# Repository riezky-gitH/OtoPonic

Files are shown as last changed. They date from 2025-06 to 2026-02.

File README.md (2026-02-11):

# Otomatisasi Hidroponik Berbasis IoT dengan Kendali Jarak Jauh dan Aplikasi Real-Time.
### Solusi Pertanian Cerdas Masa Kini
<p align="center">
  
</p>

## Daftar Isi

1. [Deskripsi Produk](https://github.com/riezky-gitH/OtoPonic#deskripsi-produk)
2. [Struktur Tim](https://github.com/riezky-gitH/OtoPonic#team-member)
3. [Tujuan Produk](https://github.com/riezky-gitH/OtoPonic#tujuan)
4. [Keunggulan Produk](https://github.com/riezky-gitH/OtoPonic#keunggulan)
5. [Potensi Pengembangan](https://github.com/riezky-gitH/OtoPonic#potensi-pengembangan)
6. [Kolaborasi & Dukungan](https://github.com/riezky-gitH/OtoPonic#kolaborasi--dukungan)
7. [Hardware](https://github.com/riezky-gitH/OtoPonic#hardware)
8. [Software](https://github.com/riezky-gitH/OtoPonic#software)
9. [Aplikasi OtoPonic](https://github.com/riezky-gitH/OtoPonic#aplikasi-otoponic)
10. [Hubungi Kami](https://github.com/riezky-gitH/OtoPonic#hubungi-kami)

## Deskripsi Produk
**OtoPonic** adalah solusi pertanian cerdas berbasis IoT yang dirancang untuk mengotomatisasikan hidroponik dengan fitur pemantauan real-time dan kendali jarak jauh melalui aplikasi atau web. Sistem ini mampu memantau berbagai parameter penting seperti pH air, kadar nutrisi, suhu air, serta batas ketinggian air dalam pipa hidroponik. OtoPonic dilengkapi dengan fitur kontrol otomatis, seperti aktivasi pompa nutrisi saat kadar terlalu rendah, pengaturan pH air dengan pompa pH up/down, dan penyiraman atau pengurasan otomatis dalam instalasi hidroponik. Selain itu, pengguna juga dapat mengontrol sistem secara manual melalui dashboard yang intuitif serta menerima notifikasi saat terjadi kondisi abnormal. Proyek ini bertujuan untuk meningkatkan efisiensi dan kenyamanan dalam bercocok tanam hidroponik, terutama bagi pengguna yang ingin memantau dan mengelola kebun mereka dari jarak jauh secara praktis dan real-time.

## Support By 
>- Dosen Pengampu : Akhmad Hendriawan ST., MT. (NIP.197501272002121003)
>- Mata kuliah : Mikrokontroller
>- Program Studi : D4 Teknik Elektronika
>- Politeknik Elektronika Negeri Surabaya<br>

## Team Member
| NRP | Nama | Jobdesk | Akun |
| :---:|:---:| :---:| :-----:|
| 2123600003 | Taufiq  |  UI/UX Designer | [Taufiq](https://github.com/Raditya-G)
| 2123600006 | Auliya | UI/UX Designer | [Auilya](https://github.com/auliyarzk/)
| 2123600017 | Brian | Programmer | [Brian](https://github.com/brianrjg)
| 2123600018 | Riezky | Project Manager | [Riezky](https://github.com/riezky-gitH)
| 2123600020 | Subkhi | Hardware Developer | [Subkhi](https://github.com/subkhiMuhammad)
| 2123600024 | Alwan | 3D Designer |[Alwan](https://github.com/alwan441)

## Foto Anggota Tim 


## Tujuan
- **Mempermudah perawatan kebun hidroponik** dengan sistem otomatis yang mengatur pH, nutrisi, dan penyiraman secara mandiri.
- **Memantau kondisi tanaman secara real-time** melalui aplikasi atau web, kapan saja dan di mana saja.
- **Memberikan kontrol penuh jarak jauh**, sehingga pengguna bisa mengelola kebun tanpa harus selalu berada di lokasi.
- **Meningkatkan efisiensi dan hasil panen** dengan pengelolaan nutrisi dan air yang lebih akurat dan stabil.
- **Cocok untuk semua kalangan**, mulai dari petani pemula hingga profesional yang ingin solusi praktis dan modern.

## Keunggulan

- **Integrasi IoT** yang kuat dengan adanya sensor dan komunikasi data berbasis GSM untuk pemantauan jarak jauh yang stabil
- **Kontrol manual & otomatis** yang dapat memberikan fleksibilitas
- **Antarmuka pengguna** yang intuitif dalam penggunaan UI/UX
- **Mendukung keberlanjutan & efisiensi energi** dalam mengurangi limbah air dan penggunaa sumber daya berlebihan

## Potensi Pengembangan OtoPonic
- **IoT Cloud** – Akses global & notifikasi real-time.
- **Peringatan WhatsApp/SMS** – Info langsung saat kondisi kritis.
- **AI & Machine Learning** – Prediksi kebutuhan nutrisi & pertumbuhan.
- **Smart City Ready** – Siap terintegrasi dengan infrastruktur kota pintar.
- **Dashboard Analytics** – Visualisasi data & performa tanaman.

## Kolaborasi & Dukungan
- **Investor Teknologi** – Skala produksi & fitur lebih canggih.
- **Startup/R&D** – Kolaborasi pengembangan sensor & AI.
- **Kampus/Inkubator** – Edukasi & riset pertanian cerdas.
- **Pemerintah & Komunitas** – Implementasi urban farming pintar.
- **UMKM & Petani Modern** – Otomatisasi untuk hasil lebih optimal.
  
## Hardware
### 1. Desain Skematik


### 2. Desain PCB


### 3. 3D Desain PCB


## Software
### 1. Blok Diagram


### 2. Diagram Arsitektur Sistem

## Aplikasi OtoPonic
### 1. Login

### 2. Dashboard

### 3. Data Riwayat

### 4. Parameter Setting
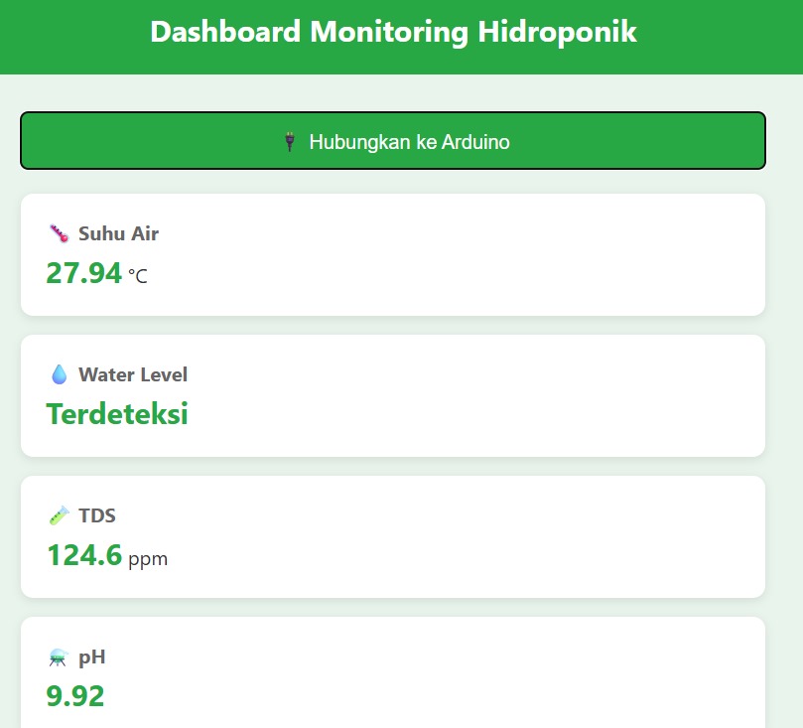
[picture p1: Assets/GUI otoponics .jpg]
)

## Hubungi Kami

Untuk kerja sama, pertanyaan, atau demo proyek:

**Email Project Manager**: [riezky.mochammad07@gmail.com](mailto:riezky.mochammad07@gmail.com)

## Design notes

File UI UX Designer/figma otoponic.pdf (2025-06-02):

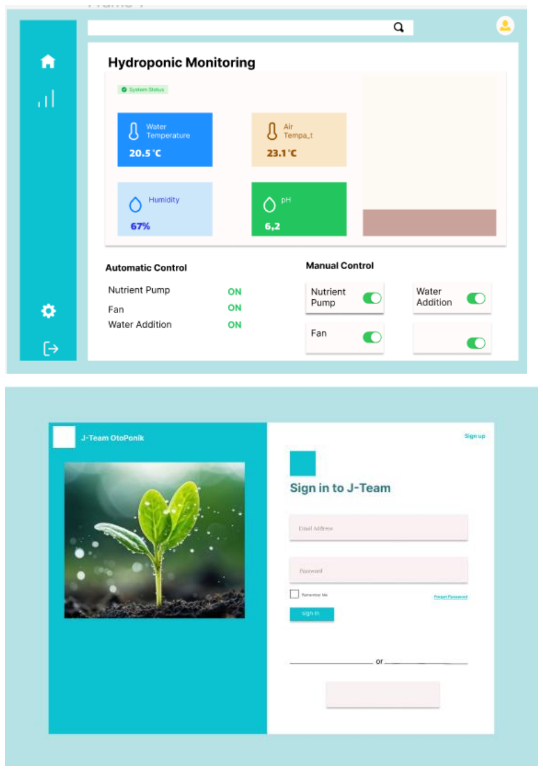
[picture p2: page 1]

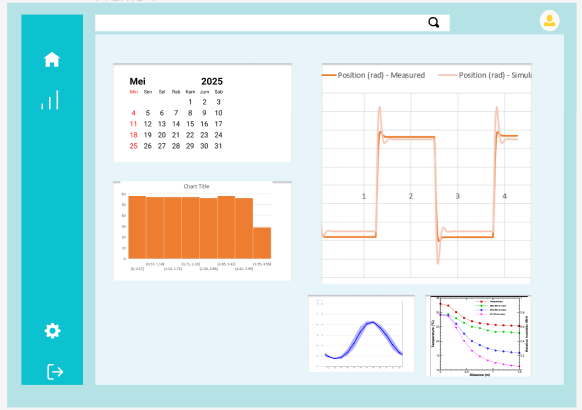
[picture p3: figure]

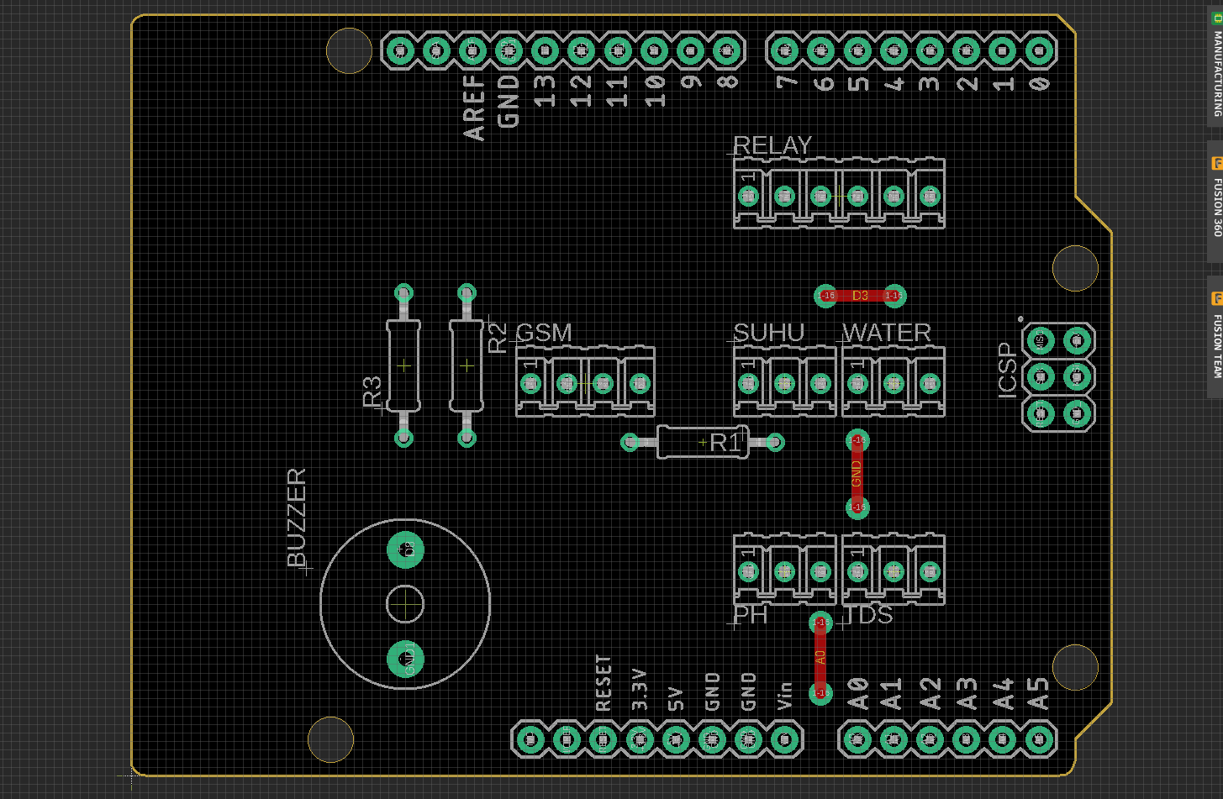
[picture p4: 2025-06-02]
Hardware/PCB/Preview Board.png

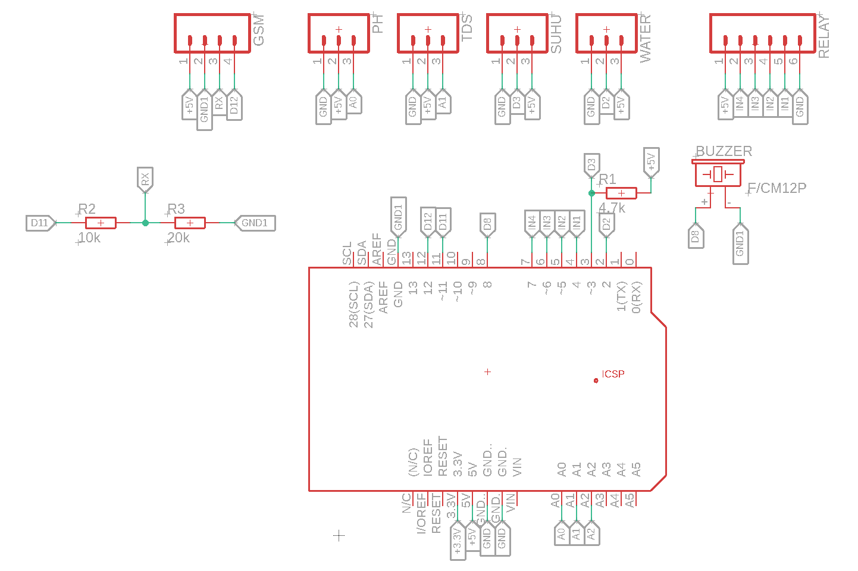
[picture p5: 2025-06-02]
Hardware/PCB/Preview Skematik.png

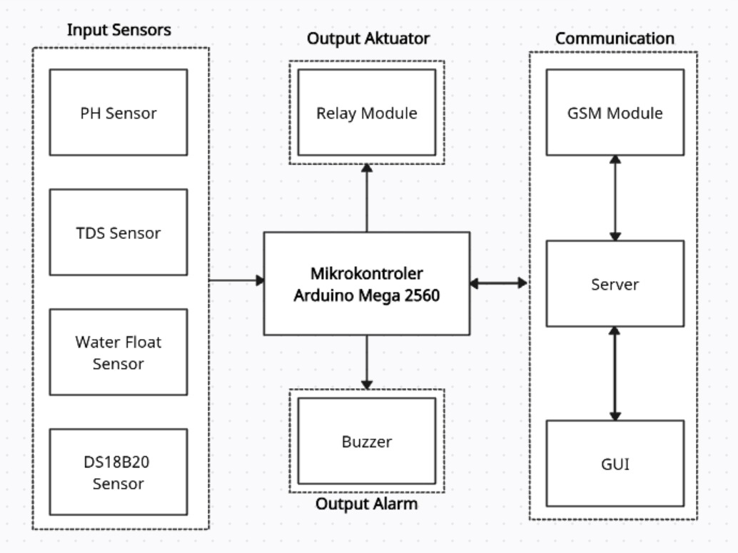
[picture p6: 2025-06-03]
Hardware/Dokumentasi Teknis/Blok Diagram.jpg

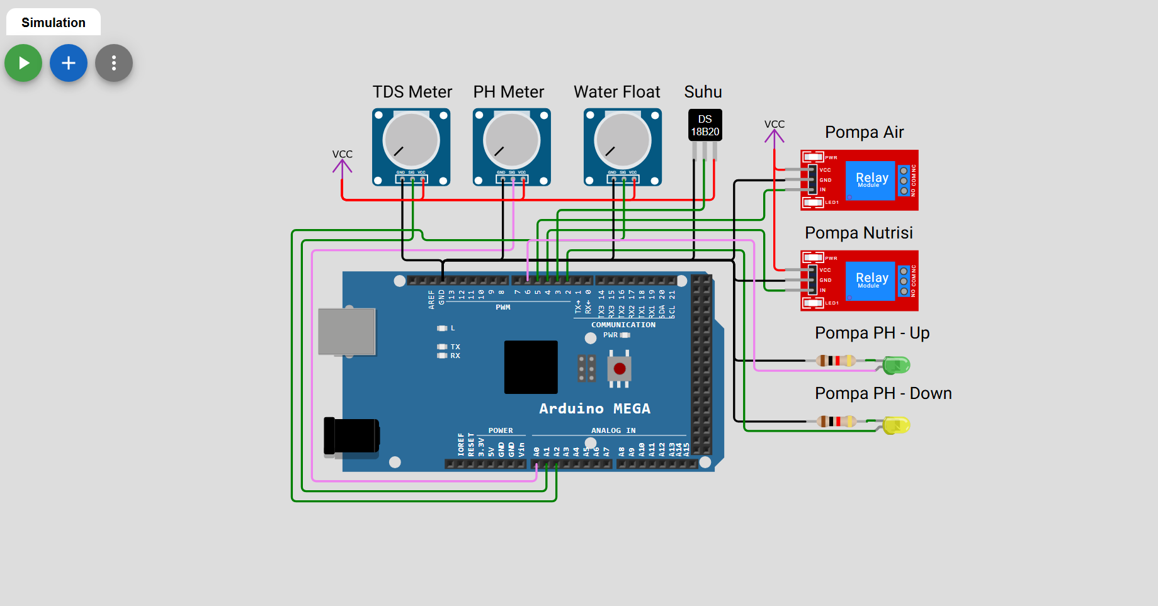
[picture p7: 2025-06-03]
Hardware/Simulasi/Preview Simulasi.png

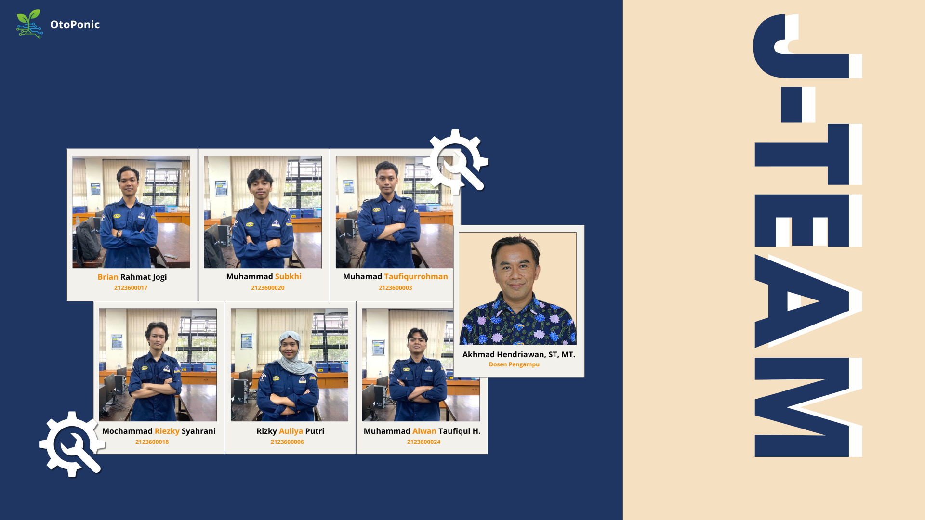
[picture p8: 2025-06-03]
Assets/PERKENALAN.png

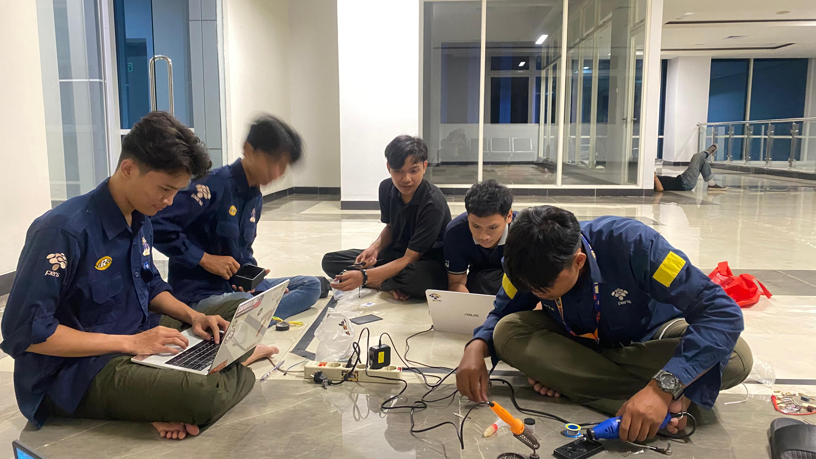
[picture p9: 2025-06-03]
Dokumentasi/WhatsApp Image 2025-06-02 at 21.11.24_5e70824d.jpg

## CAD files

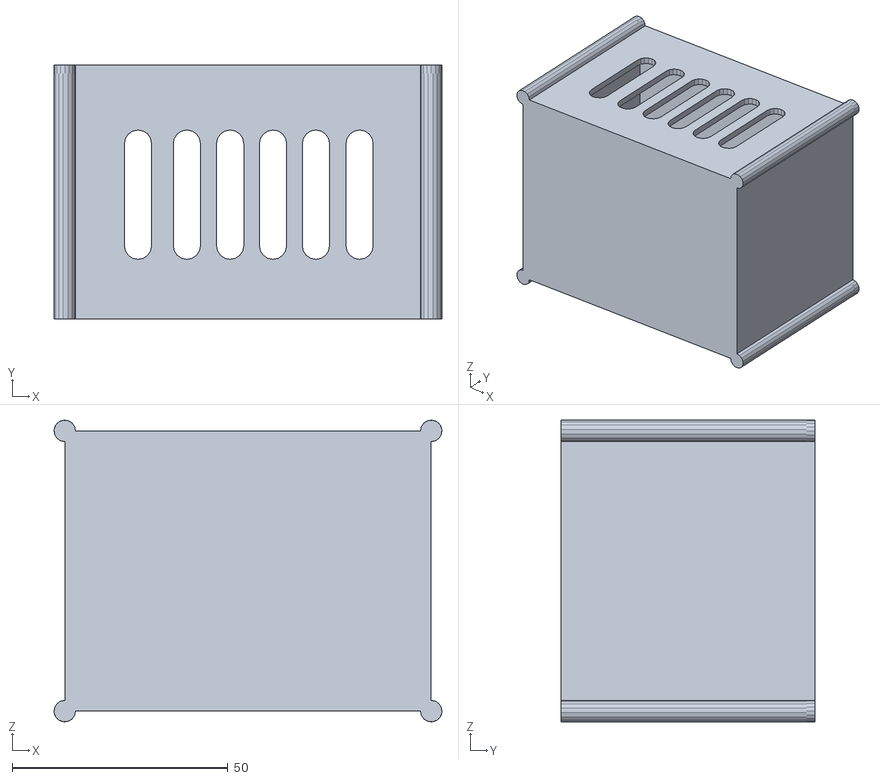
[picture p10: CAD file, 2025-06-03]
Design Product/3ddesain/alwan/Assembly1.stl
90.0 x 59.0 x 70.0

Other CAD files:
Design Product/3ddesain/alwan/Assembly1.iam
Design Product/3ddesain/alwan/Body_Bottom.ipt
Design Product/3ddesain/alwan/Part2.ipt

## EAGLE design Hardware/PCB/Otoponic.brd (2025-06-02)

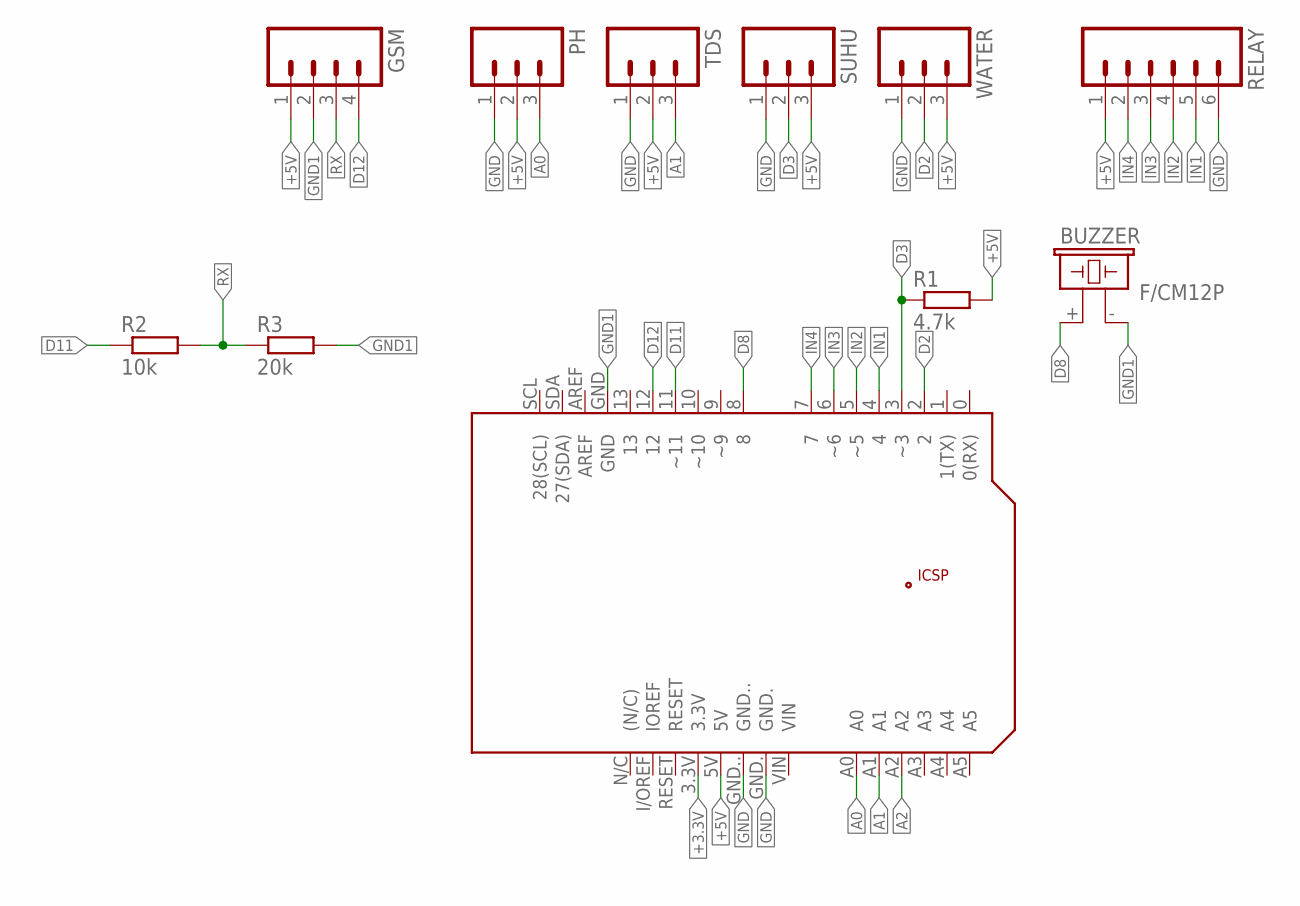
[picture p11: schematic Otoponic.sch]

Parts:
BUZZER: F/CM12P
GSM: M04; 04P
PCB2: ARDUINO_UNO
PH: M03; 03P
R1: 4.7k; 0207/10
R2: 10k; 0207/10
R3: 20k; 0207/10
RELAY: M06; 06P
SUHU: M03; 03P
TDS: M03; 03P
WATER: M03; 03P

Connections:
+3.3V: PCB2.3.3V
+5V: GSM.1, PCB2.5V, PH.2, R1.2, RELAY.1, SUHU.3, TDS.2, WATER.3
A0: PCB2.A0, PH.3
A1: PCB2.A1, TDS.3
A2: PCB2.A2
D2: PCB2.2, WATER.2
D3: PCB2.3 (~3), R1.1, SUHU.2
D8: BUZZER.+ (1), PCB2.8
D11: PCB2.11 (~11), R2.1
D12: GSM.4, PCB2.12
GND: PCB2.GND., PCB2.GND.., PH.1, RELAY.6, SUHU.1, TDS.1, WATER.1
GND1: BUZZER.- (2), GSM.2, PCB2.GND, R3.2
IN1: PCB2.4, RELAY.5
IN2: PCB2.5 (~5), RELAY.4
IN3: PCB2.6 (~6), RELAY.3
IN4: PCB2.7, RELAY.2
RX: GSM.3, R2.2, R3.1

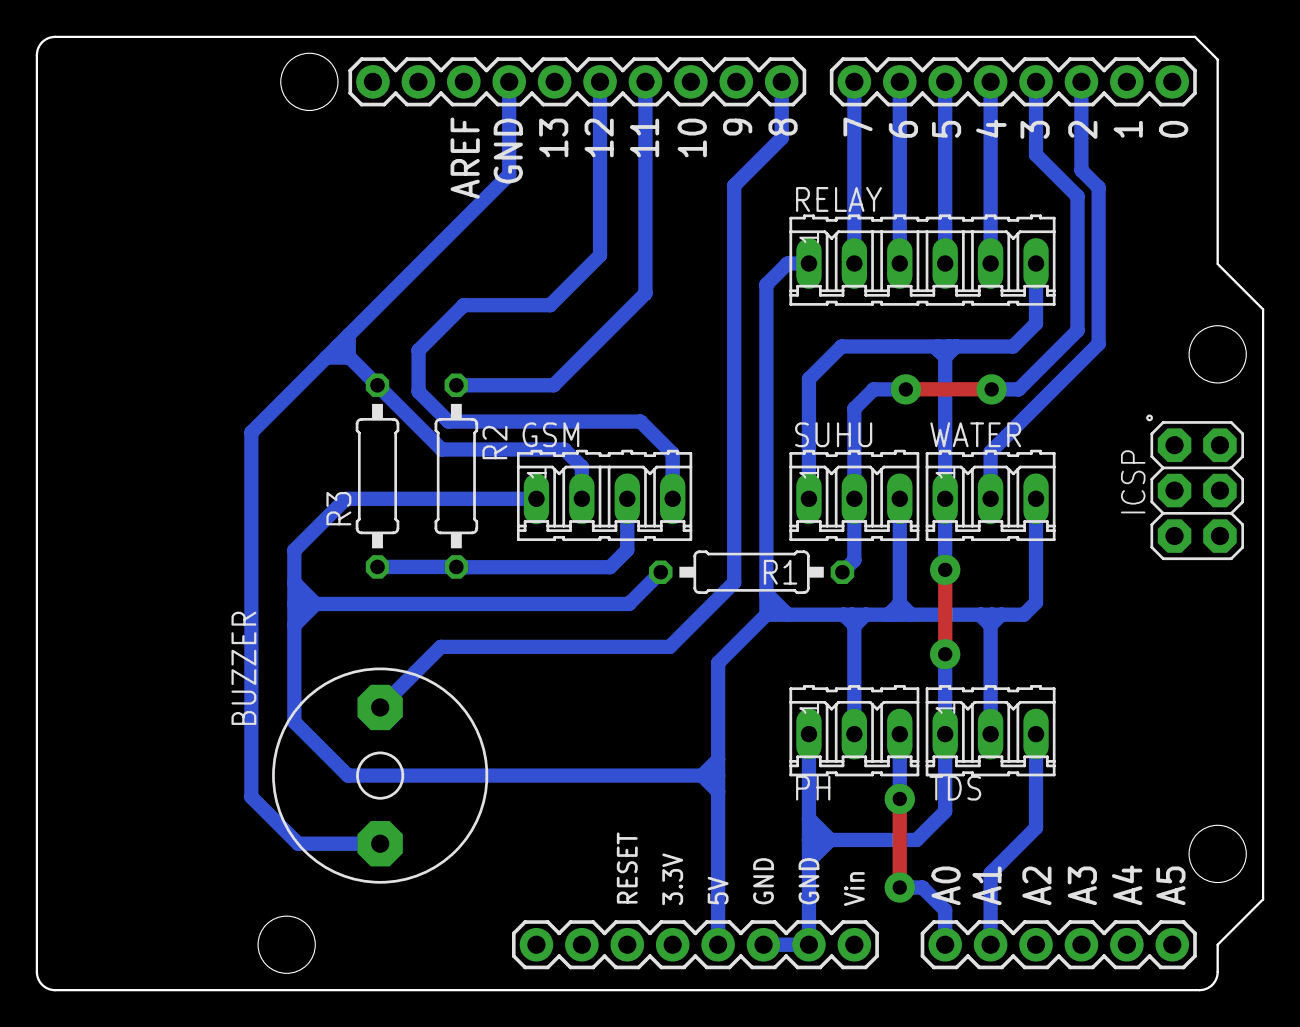
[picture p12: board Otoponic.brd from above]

Board: 2 copper layers, 68.6 x 53.3 mm, 11 parts (0 on the bottom side), 15 nets.

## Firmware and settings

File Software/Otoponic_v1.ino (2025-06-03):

#include <OneWire.h>
#include <DallasTemperature.h>

// -------------------- PIN SETUP --------------------
#define ONE_WIRE_BUS 3         // DS18B20 (Suhu)
const int buzzerPin = 8;       // Buzzer untuk suhu

const int waterLevelPin = 2;   // Sensor water level
const int relayWaterPin = 4;   // Relay air (D4)

const int tdsPin = A1;         // Sensor TDS
const int relayTdsPin = 5;     // Relay TDS (D5)

const int phPin = A0;          // Sensor pH
const int relayBasePin = 6;    // Relay cairan basa (D6)
const int relayAcidPin = 7;    // Relay cairan asam (D7)

// -------------------- THRESHOLD SETUP --------------------
// Bisa diubah sesuai kebutuhan
float suhuMin = 24.0;
float suhuMax = 30.0;

int tdsThreshold = 300;

float phLow = 5.5;
float phHigh = 6.5;

// -------------------- SENSOR SETUP --------------------
OneWire oneWire(ONE_WIRE_BUS);
DallasTemperature sensors(&oneWire);

void setup() {
  Serial.begin(9600);
  sensors.begin();

  // Setup pin
  pinMode(buzzerPin, OUTPUT);
  pinMode(waterLevelPin, INPUT);
  pinMode(relayWaterPin, OUTPUT);
  pinMode(tdsPin, INPUT);
  pinMode(relayTdsPin, OUTPUT);
  pinMode(phPin, INPUT);
  pinMode(relayBasePin, OUTPUT);
  pinMode(relayAcidPin, OUTPUT);

  // Matikan semua output awal
  digitalWrite(buzzerPin, LOW);
  digitalWrite(relayWaterPin, LOW);
  digitalWrite(relayTdsPin, LOW);
  digitalWrite(relayBasePin, LOW);
  digitalWrite(relayAcidPin, LOW);

  Serial.println("Semua sensor siap.");
}

void loop() {
  // -------------------- SENSOR SUHU --------------------
  sensors.requestTemperatures();
  float temperatureC = sensors.getTempCByIndex(0);
  Serial.print("Suhu: ");
  Serial.print(temperatureC);
  Serial.println(" °C");

  if (temperatureC < suhuMin || temperatureC > suhuMax) {
    digitalWrite(buzzerPin, HIGH);
  } else {
    digitalWrite(buzzerPin, LOW);
  }

  // -------------------- SENSOR WATER LEVEL --------------------
  int waterStatus = digitalRead(waterLevelPin);
  if (waterStatus == HIGH) {
    Serial.println("Water level: Terdeteksi");
    digitalWrite(relayWaterPin, LOW); // Relay OFF (karena air ada)
  } else {
    Serial.println("Water level: Tidak ada air");
    digitalWrite(relayWaterPin, HIGH); // Relay ON (karena air habis)
  }

  // -------------------- SENSOR TDS --------------------
  int rawTds = analogRead(tdsPin);
  float tdsValue = (rawTds * 500.0) / 1023.0;
  Serial.print("TDS: ");
  Serial.print(tdsValue, 1);
  Serial.println(" ppm");

  if (tdsValue < tdsThreshold) {
    digitalWrite(relayTdsPin, HIGH);  // ON
  } else {
    digitalWrite(relayTdsPin, LOW);   // OFF
  }

  // -------------------- SENSOR pH --------------------
  int rawPh = analogRead(phPin);
  float voltagePh = rawPh * (5.0 / 1023.0);
  float phValue = 7.0 + ((2.5 - voltagePh) / 0.18);

  Serial.print("pH: ");
  Serial.println(phValue, 2);

  if (phValue < phLow) {
    digitalWrite(relayBasePin, HIGH);
    digitalWrite(relayAcidPin, LOW);
  } else if (phValue > phHigh) {
    digitalWrite(relayBasePin, LOW);
    digitalWrite(relayAcidPin, HIGH);
  } else {
    digitalWrite(relayBasePin, LOW);
    digitalWrite(relayAcidPin, LOW);
  }

  Serial.println("-------------------------------------------------");
  delay(1000);
}

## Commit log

2025-06-02 File PCB
    File Skematik dan File Board
    [Otoponic.brd, Otoponic.sch]
2025-06-02 Preview
    Preview desain Skematik dan PCB
2025-06-03 Link Simulasi
    Link simulasi yang ada di wokwi
